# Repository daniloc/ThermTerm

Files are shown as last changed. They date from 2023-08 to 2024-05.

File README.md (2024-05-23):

# ThermTerm: an open source heat pump controller and home automation terminal, built on ESP32

264734232-c3d5e749-000b-4d88-8361-5ec403e4682f

**Control heat pumps manually or remotely via MQTT/Home Assistant**.

I love my heat pumps. They're energy efficient and the fastest way to heat or cool any room.

But I've always hated the remote controls that come with heat pumps. They're clunky and hard to read, especially in low light. In theory, you can program schedules for your heat pumps, but in practice the remotes are too frustrating to use for that.

ThermTerm solves all the problems I've had with these physical controls, while integrating the heat pumps into Home Assistant via MQTT. Additional sensors pipe temperature, humidity and light data, for statistics and automation. Out of the box, ThermTerm supports Mitsubishi's infrared protocol, since that's the system I have. Thanks to integration with [IRRemoteESP8266](https://github.com/crankyoldgit/IRremoteESP8266), you can make ThermTerm work with [your own heat pumps](https://github.com/crankyoldgit/IRremoteESP8266/blob/master/SupportedProtocols.md) by writing a few lines of adaptor code. No signal analysis or reverse-engineering required. See [Customization](#customization) for more details.

**Note: you will need [PlatformIO](https://platformio.org) to get started.**

## Interface

Diagram

Press the dial to toggle power.

Turn the dial to set temperature.

Change to heat mode with the bottom button, cool mode with the top. Set fan speed by pressing the center button, then turn the dial.

Through a TFT screen, readouts are visible any time of day. The chunky dial is easy to press without looking. Program automations using Home Assitant, not miserable rubber buttons like a VCR. Toggle your heat pumps from any room in the house, or even while you're away.

## Goals

- Make a heat pump controller I don't hate using
- Use easy-to-repurpose IR, instead of a manufacturer-specific serial connection
- Structure this project into discrete objects to make iteration, maintenance and enhancements easy
- Provide hobbyists with a reference for Arduino code with that kind of structure (I had a hard time finding it for end projects, only libraries)
- Build a device that expands the surface area of a home automation system, letting it gather more data, take more user input, and provide more feedback
- Leverage as much of the existing Arduino OSS code ecosystem as possible, keeping the project tightly scoped to its problem domain

## Shoutouts/core dependencies

- [Adafruit](https://learn.adafruit.com), whose thorough libraries and thoughtful breakout boards made hardware integration a breeze
- [`IRRemoteESP8266`](https://github.com/crankyoldgit/IRremoteESP8266), a library with bulletproof software-based PWM, a great API, and a shocking compendium of IR protocols
- [`arduino-home-assistant`](https://github.com/dawidchyrzynski/arduino-home-assistant), an MQTT library with exhaustive implementations of Home Assistant-supported devices

## Bill of materials

- [Adafruit ESP32-S3 Feather Reverse TFT](https://www.adafruit.com/product/5691)
- [Adafruit I2C rotary encoder board with Neopixel](https://www.adafruit.com/product/4991)
- [Rotary encoder](https://www.adafruit.com/product/377)
- [IR blaster board](https://www.adafruit.com/product/5639)
- Optional: 5mm IR LED
- Optional: [Tiny piezo buzzer](https://www.adafruit.com/product/1740), for auditory feedback now (and later: alerts)
- Optional: [400 mAh LiPo battery](https://www.adafruit.com/product/3898), so the devices can still communicate with HA during a power outage
- [SHTC3 Temperature/humidity sensor](https://www.adafruit.com/product/4636)
- [BH1750 Light sensor](https://www.adafruit.com/product/4681)
- 1 [100mm StemmaQT/Qwiic cable](https://www.adafruit.com/product/4210)
- 2 [50mm StemmaQT/Qwiic cables](https://www.adafruit.com/product/4399)
- Wires for the IR blaster (I trimmed one of [these](https://www.adafruit.com/product/4336))
- USB-C cable ([right angle designs](https://www.amazon.com/dp/B08912ZBHZ) look best)
- A 5v USB power supply
- Opaque PETG to print the main case
- Translucent PETG to print the dial
- [Velcro/picture hanging Command Strip](https://www.amazon.com/Command-Picture-Decorate-Damage-Free-PH206-14NA/dp/B073XR4X72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) to wall-mount

The sensors use I2C, so with a light rewrite, you can replace the above models with alternatives if needed, or skip them entirely if you don't care about recording data back to Home Assistant.

If you want to design your own enclosure and use a different display, I suspect any ESP32-based device will work fine.

There's not a huge upside to the battery in the current implementation but I designed the case to accommodate it for future enhancements. You can skip it unless you want to tinker with power outage-related home automation tasks.

## Configuration

Make a copy of [`_Credentials.h.example`](/src/_Credentials.h.example), rename it to `_Credentials.h`. This file will be ignored by git.

Fill in these values as appropriate to your network:

```C++
#define WIFI_SSID ""       // your network SSID (name)
#define WIFI_PASSWORD "" // your network password

#define MQTT_LOGIN ""
#define MQTT_PASSWORD ""

#define MQTT_BROKER IPAddress(192, 168, 1, 100)
```

## Home Assistant

With correct MQTT credentials, ThermTerm should be discovered automatically in the Home Assistant MQTT configuration.

**To troubleshoot, uncomment this line in `platfomio.ini`:**

```yaml
build_flags = -D ARDUINOHA_DEBUG
```

This will log MQTT events and errors via serial.

## Customization

The most urgent customization for most will be making this work with your own heat pump.

1. Write a subclass of [`IRInterface`](/src/hardware/infrared/IRInterface.h). You can use [`MistubishiInterface`](https://github.com/daniloc/ThermTerm/blob/main/src/hardware/infrared/MitsubishiInterface.cpp) as a starting point. The goal is to translate the system controller's state model into whatever features you care about for your own heat pump. Consult IRremoteESP8266 for [the API that corresponds to your manufacturer](https://github.com/crankyoldgit/IRremoteESP8266/blob/master/SupportedProtocols.md).
2. In `main.cpp`, replace the `MitsubishiInterface` instance in the `SystemController` constructor with your own interface:

```C++
    YourCustomInterface customInterface;
    SystemController controller(customInterface);
```

That should get you moving.

To tweak other details about the device, explore `_Constants.h`. To adapt this to alternative hardware, including other displays, you'll want to replace the implementations in `src/hardware`.

## Assembly

If you want to go all-in and asemble one of these for yourself, 3D printing files have been provided. See [ASSEMBLY.md](/enclosure/ASSEMBLY.md) for detailed instructions.

## Roadmap

There's a lot more this platform could do, but this is the minimally-useful implementation that can get your whole heat pump system integrated in with an afternoon of work. Future features:

- [ ] Celsius support (what can I say, I think in Fahrenheit)
- [ ] Display alerts issued from Home Assistant
- [ ] Trigger alerts distributed to all other ThermTerm devices on the network
- [ ] Set preferences, including WiFi and MQTT credentials, via serial terminal
- [ ] Bulk provisioning

## Contributions

If you have anything useful you'd like to give back, feel free. Of particular interest:

- A simple Celsius toggle. A preprocessor macro would be fine to start with. All the internal state is managed in Celsius, and `SystemState` already has partial support for it.
- I can only test with Mitsubishi 144-bit IR receivers, since that's all I have. If you have a working interface for a different manufacturer, open a PR to add it!
- This is the most C++ I've ever written. If there's anything goofy that could be done differently, feel free to propose it
- Relatedly, if you have thoughts on making this project more extensible with other displays and ESP32 variants, I'd love to hear about it
- Enhancements to documentation, or comments on code you found confusing, are great too

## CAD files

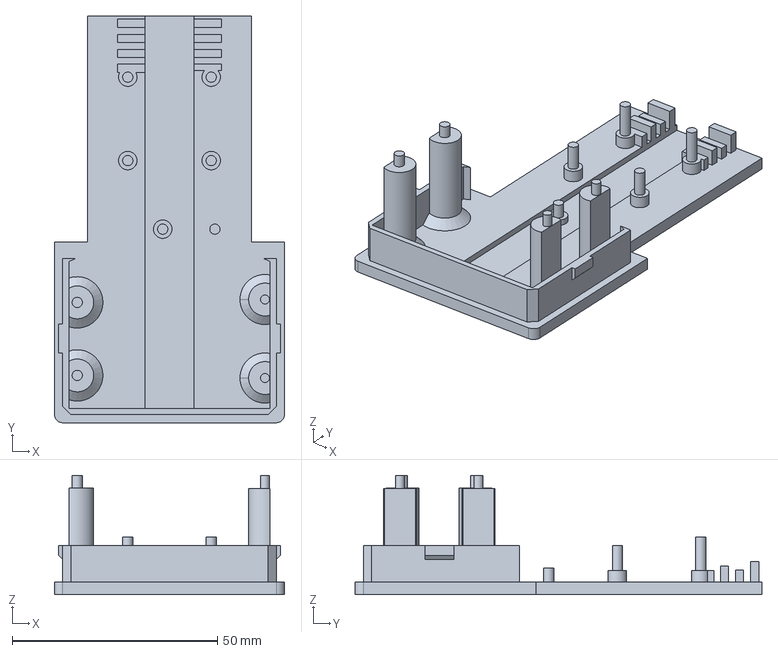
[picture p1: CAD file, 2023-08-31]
enclosure/ThermTerm case 1.2_Base plate.step
56.0 x 99.0 x 29.0 mm

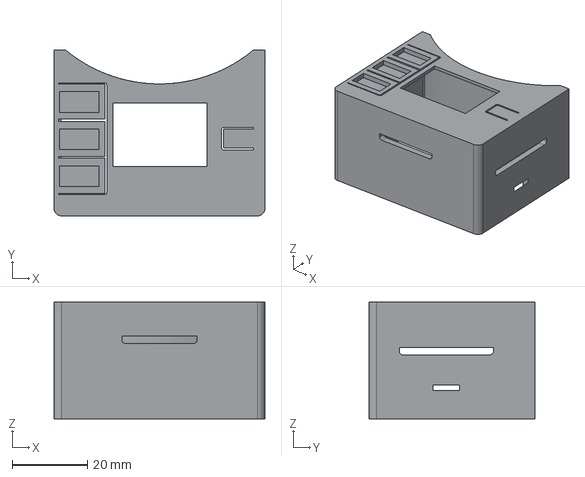
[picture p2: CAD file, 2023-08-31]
enclosure/ThermTerm case 1.2_Top case.step
56.0 x 44.0 x 31.0 mm

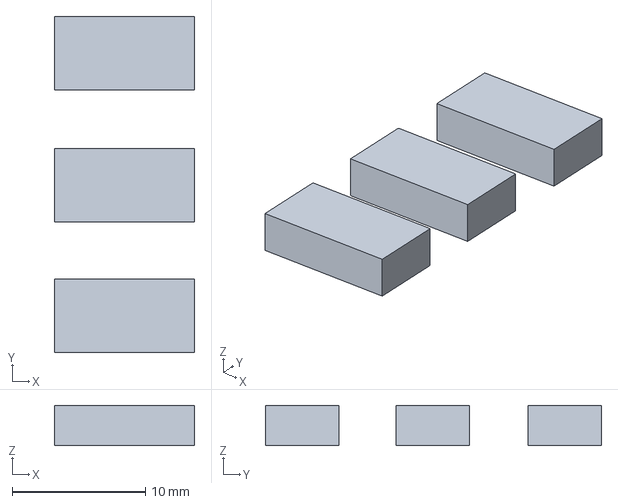
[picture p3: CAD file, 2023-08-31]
enclosure/ThermTerm case 1.2_Keycaps.step
10.5 x 25.2 x 3.00 mm

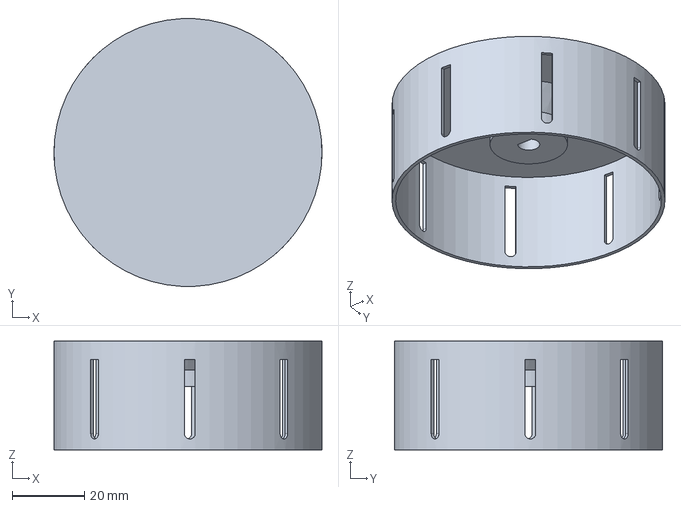
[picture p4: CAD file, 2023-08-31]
enclosure/ThermTerm case 1.2_Knob.step
74.0 x 74.0 x 30.0 mm

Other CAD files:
enclosure/ThermTerm case 1.2_Base plate.stl
enclosure/ThermTerm case 1.2_Keycaps.stl
enclosure/ThermTerm case 1.2_Knob.stl
enclosure/ThermTerm case 1.2_Top case.stl

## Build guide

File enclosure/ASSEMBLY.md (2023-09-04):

# Assembly

To build your own ThermTerm, follow along.

## Circuit

ThermTerm relies mostly on I2C devices, so you can connect them together in whatever order you want. You can affix these components to a piece of cardboard to test things out and ensure everything is doing what you expect.

264531564-6f04c1c9-9900-47f6-958d-a4b7f66801d4

If you'd like to use the included enclosure design, this sequence works best:

Circuit diagram

By default, the infrared signal pin is `A0`, while the piezo signal is on `A1`. Change these in `_Constants.h` if needed. Oddly, the Feather only has a single ground pin on the board proper, so I snuck the piezo's ground wire into the IR blaster ground's solder blob. Seems to be fine.

## 3D printing

For something you can mount to the wall, a case design is provided. You'll want to orient all parts with their flattest faces against the print bed.

Printing layout example

The design looks and works great using draft-quality layers at 0.3mm, but **you'll want to use PETG for the print**. While prototyping the case, I found PLA to be too brittle for the various posts that hold the components in place.

If your bridging is well tuned, you shouldn't need supports.

The knob/dial piece really should be printed with translucent PETG. This allows you to see the status light on the rotary encoder, and it's probably important for the IR signal to escape as well. If you want to be fancy, it's nice to ask your slicer for a more interesting bottom infill pattern, since light will shine through it. In PrusaSlicer, I chose `Octagram Spiral`.

## Assembly

To use the included case design, wire up the components as described above. Sensors are held in place by slots, while posts hold the IR blaster, rotary encoder, and ESP32 board in place.

The IR blaster leads should be trimmed to around 50mm.





I affixed the small piezo buzzer to the metal RF shield on the ESP32 board to keep it out of the way.



The rotary encoder breakout gets a lot of impact, so I'd suggest anchoring it in place by melting the bottom two posts with a soldering iron.



To manage the StemmaQT cables, use the raceway molded into the base to tuck the longest cable run, from ESP32 to the light sensor. For the shorter cables, fold them gently against the case to prevent the dial scraping against them.



If desired, print the key caps and press-fit them into the rectangular recesses on the buttons in front of the case. I found it helped to remove the front face, position the key caps as best I could manage, then place the shell face down and gently press against the insides of the button tabs with the rubberized handle-end of some pliers. This clicked the keycaps into place without bending the tabs.



Pop on the dial, and you're done.

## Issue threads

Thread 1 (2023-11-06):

Compatible Heat Pumps

JacobChrist, 2023-11-06:
It would be nice if you had a list of compatible heat pumps that you have tested this device with.  It sounds like you are using room scale units.  I have a large house with small bedrooms and I have been thinking about putting in room scale AC's so that I don't have to cool the huge house at night when the vast majority of the space is unoccupied.

Nice project!  I want to do something similar but I'll probably use something like this [EarthLCD 303 with a Pico Pi](https://github.com/earthlcd/EarthPK-3x) display  which I already have working with [PicoW_HomeAssistant_Starter](https://github.com/daniloc/PicoW_HomeAssistant_Starter).

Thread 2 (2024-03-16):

Modified the base model to screw on components

ecodad, 2024-03-16:
I modified your model to be able to screw on 3 of the boards with m2.5x4 screws.

I posted the stl on [Printables](https://www.printables.com/model/807892-modified-thermterm-base), let me know if you want me to change anything in the description or attribution.  I included your license as a text file.
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

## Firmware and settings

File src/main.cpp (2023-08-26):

#include <Arduino.h>
#include <Adafruit_ST7789.h>

#include "views/BaseView.h"
#include "hardware/Display.h"
#include "hardware/EnvSensor.h"
#include "hardware/Audio.h"
#include "hardware/input/Input.h"
#include "hardware/infrared/MitsubishiInterface.h"

#include "views/StatusView.h"
#include "SystemController.h"

#include "hardware/WifiInterface.h"
#include <WiFi.h>

MitsubishiInterface mitsubishiInterface; // Create alternative IR schemes by sublassing IRInterface
SystemController controller(mitsubishiInterface);

EnvSensor sensor = EnvSensor();

Input &input = Input::shared();
Adafruit_ST7789 &tft = Display::shared().configure();
StatusView statusView(tft, controller);
BaseView &activeView = statusView;

void handleInput(UserInput input)
{
  Serial.print(F("forwarded input"));
  activeView.handleInputEvent(input);
}

void updateEnvironmentData(float temp, float humidity, float lux)
{

  if (temp != controller.getState().temperature ||
      humidity != controller.getState().humidity ||
      lux != controller.getState().lux)
  {
    controller.setHumidity(humidity);
    controller.setTemperature(temp);
    controller.setLux(lux);
    statusView.draw();
  }

  if (controller.shouldDimScreen())
  {
    Display::shared().dimScreen();
  }
  else
  {
    Display::shared().brightScreen();
  }
}

void setup(void)
{
  Serial.begin(9600);
  Serial.print(F("Hello! Feather TFT Test"));

  sensor.setCallback(updateEnvironmentData);
  input.setCallback(handleInput);

  sensor.configure();
  input.configure();
  statusView.draw();

  Audio::configure();

  WifiInterface::shared().configure();
  controller.configure();
}

void loop()
{
  sensor.heartbeat();
  input.heartbeat();
  controller.heartbeat();
  statusView.heartbeat();
}

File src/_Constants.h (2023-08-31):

#ifndef SRC_CONSTANTS
#define SRC_CONSTANTS

#include <Arduino.h>

#define INFRARED_PIN A0

#define HVAC_MAX_TEMP 31 // Celsius values
#define HVAC_MIN_TEMP 16

#define DIM_SCREEN_CUTOFF_LUX 5 // What light value should turn off the mode indicator and dim the screen?

#define PWM_TONE_CHANNEL 2 // Get off the main PWM channel, or LED pulses will leak out the speaker
#define PIEZO_PIN A1
#define PIEZO_BASE_FREQUENCY 200

#define UI_CHIRP_NOTE_LENGTH 25

#define SCREEN_WIDTH 240  // display width, in pixels
#define SCREEN_HEIGHT 135 // display height, in pixels

#define ENV_SENSOR_INTERVAL 5 // Seconds between polling the sensors

const int BUTTON0_PIN = 0;
const int BUTTON1_PIN = 1;
const int BUTTON2_PIN = 2;

#define VERSION_NUMBER "0.2"

#define ROTARY_ENCODER_ADDRESS 0x36
#define ENCODER_SWITCH_PIN 24
#define ENCODER_NEOPIXEL_PIN 6

#endif // SRC_CONSTANTS

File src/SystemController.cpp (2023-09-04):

#include "hardware/infrared/MitsubishiInterface.h"
#include "hardware/Audio.h"
#include "SystemController.h"
#include "_Constants.h"

#include <functional>

SystemController *SystemController::instance = nullptr; // Initialize static member

float setPointStep = 1;

SystemController::SystemController(IRInterface &irInterface) : haInterface_(HAInterface()),
                                                           irInterface_(irInterface)
{
    instance = this;
}

bool SystemController::shouldDimScreen()
{
    return state_.lux < DIM_SCREEN_CUTOFF_LUX;
}

void SystemController::scheduleUpdate()
{
    needsUpdate = true;
    batchScheduleTime = 0;
}

void SystemController::checkInputBatching()
{
    if (!needsUpdate)
        return;

    if (batchScheduleTime == 0)
    {
        batchScheduleTime = millis();
        return;
    }

    if (millis() - batchScheduleTime >= 2000)
    {
        sendInfraredCommand();
        needsUpdate = false;
        batchScheduleTime = 0;
    }
}

void SystemController::sendInfraredCommand()
{
    irInterface_.sendCommand(state_.hvacCommand());
}

HvacMode convertMode(HAHVAC::Mode mode)
{
    switch (mode)
    {
    case HAHVAC::AutoMode:
        return HVAC_AUTO;
    case HAHVAC::CoolMode:
        return HVAC_COLD;
    case HAHVAC::HeatMode:
        return HVAC_HOT;
    case HAHVAC::DryMode:
        return HVAC_DRY;
    case HAHVAC::FanOnlyMode:
        return HVAC_FAN;
    default:
        return HVAC_AUTO; // default value
    }
}

HAHVAC::Mode reverseConvertMode(HvacMode mode)
{
    switch (mode)
    {
    case HVAC_AUTO:
        return HAHVAC::AutoMode;
    case HVAC_COLD:
        return HAHVAC::CoolMode;
    case HVAC_HOT:
        return HAHVAC::HeatMode;
    case HVAC_DRY:
        return HAHVAC::DryMode;
    case HVAC_FAN:
        return HAHVAC::FanOnlyMode;
    default:
        return HAHVAC::AutoMode; // default value
    }
}

HvacFanMode convertFanMode(HAHVAC::FanMode haFanMode)
{
    switch (haFanMode)
    {
    case HAHVAC::AutoFanMode:
        return FAN_SPEED_AUTO;
    case HAHVAC::LowFanMode:
        return FAN_SPEED_1;
    case HAHVAC::MediumFanMode:
        return FAN_SPEED_3;
    case HAHVAC::HighFanMode:
        return FAN_SPEED_4;
    default:
        return FAN_SPEED_AUTO;
    }
}

void SystemController::handleRemoteModeChange(HAHVAC::Mode newMode, HAHVAC *sender)
{
    if (newMode == HAHVAC::Mode::OffMode)
    {
        state_.power = OFF;
    }
    else
    {
        state_.hvacMode = convertMode(newMode);
        state_.power = ON;
    }

    sender->setMode(newMode);
    sendInfraredCommand();
    notifyObservers();
}

void SystemController::handleRemotePowerChange(bool powerState, HAHVAC *sender)
{
    if (powerState)
    {
        state_.power = ON;
        haInterface_.getHVACDevice().setMode(sender->getCurrentMode());
    }
    else
    {
        state_.power = OFF;
        haInterface_.getHVACDevice().setMode(HAHVAC::Mode::OffMode);
    }

    sendInfraredCommand();
    notifyObservers();
}

void SystemController::handleRemoteFanModeChange(HAHVAC::FanMode fanMode, HAHVAC *sender)
{
    Serial.print("updating fan mode" + String(fanMode));
    state_.fanSpeed = convertFanMode(fanMode);
    state_.power = ON;
    sender->setFanMode(fanMode);
    sendInfraredCommand();
    notifyObservers();
}

void SystemController::handleRemoteTargetTemperatureChange(HANumeric temperature, HAHVAC *sender)
{
    Serial.print("receiving remote temperature change");
    setSetPoint(temperature.toFloat());
}

void SystemController::configure()
{
    irInterface_.configure();
    haInterface_.configure(state_.celsius);

    haInterface_.getHVACDevice().onModeCommand(&SystemController::staticHandleRemoteModeChange);
    haInterface_.getHVACDevice().onPowerCommand(SystemController::staticHandleRemotePowerChange);
    haInterface_.getHVACDevice().onFanModeCommand(SystemController::staticHandleRemoteFanModeChange);
    haInterface_.getHVACDevice().onTargetTemperatureCommand(SystemController::staticHandleRemoteTargetTemperatureChange);

    haInterface_.getAlertTrigger().onCommand(SystemController::staticHandleAlert);
}

// getters
SystemState SystemController::getState() { return state_; };

// setters
void SystemController::setTemperature(float temperature)
{
    if (temperature != state_.temperature)
    {
        state_.temperature = temperature;
        haInterface_.getTemperatureSensor().setValue(temperature);
        Serial.print(F("logging temp update"));
    }
}

void SystemController::setHumidity(float humidity)
{
    if (humidity != state_.humidity)
    {
        state_.humidity = humidity;
        haInterface_.getHumiditySensor().setValue(humidity);
        Serial.print(F("logging humidity update"));
    }
}

void SystemController::setLux(float lux)
{
    if (lux != state_.lux)
    {
        state_.lux = lux;
        haInterface_.getLightSensor().setValue(lux);
        Serial.print(F("Logging light update"));
    }
}

void SystemController::setSetPoint(float setPoint)
{
    if (setPoint != state_.getSetPointUIValue())
    {
        state_.updateSetPoint(setPoint);
        haInterface_.getHVACDevice().setTargetTemperature(setPoint);
        scheduleUpdate();
        notifyObservers();
    }
}

void SystemController::setHVACMode(HvacMode hvacMode)
{

    state_.hvacMode = hvacMode;
    state_.power = ON;
    haInterface_.getHVACDevice().setMode(reverseConvertMode(hvacMode));
    sendInfraredCommand();
    notifyObservers();
}

void SystemController::setFanSpeed(HvacFanMode fanSpeed)
{

    state_.fanSpeed = fanSpeed;
    scheduleUpdate();
}

void SystemController::incrementSetPoint()
{
    float setPoint = state_.getSetPointUIValue();
    setPoint += setPointStep;
    setSetPoint(setPoint);
    Audio::play_UpwardTone();
}

void SystemController::decrementSetPoint()
{
    float setPoint = state_.getSetPointUIValue();
    setPoint -= setPointStep;
    setSetPoint(setPoint);
    Audio::play_DownwardTone();
}

void SystemController::togglePower()
{

    if (state_.power == ON)
    {
        state_.power = OFF;
        haInterface_.getHVACDevice().setMode(HAHVAC::Mode::OffMode);
    }
    else
    {
        state_.power = ON;
        haInterface_.getHVACDevice().setMode(reverseConvertMode(state_.hvacMode));
    }

    needsUpdate = false;
    sendInfraredCommand();
    notifyObservers();
}

void SystemController::heartbeat()
{
    haInterface_.heartbeat();
    checkInputBatching();
}

// Static->Instance bridging
void SystemController::staticHandleRemotePowerChange(bool powerState, HAHVAC *sender)
{
    if (instance)
    {
        instance->handleRemotePowerChange(powerState, sender);
    }
}

void SystemController::staticHandleRemoteFanModeChange(HAHVAC::FanMode fanMode, HAHVAC *sender)
{
    if (instance)
    {
        instance->handleRemoteFanModeChange(fanMode, sender);
    }
}
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

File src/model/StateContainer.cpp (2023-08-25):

#include "hardware/MitsubishiInterface.h"
#include "hardware/Audio.h"
#include "StateContainer.h"

#include <functional>

#define DIM_SCREEN_CUTOFF_LUX 1

StateContainer *StateContainer::instance = nullptr; // Initialize static member

MitsubishiInterface mitsubishiSend;

float setPointStep = 1;

bool StateContainer::shouldDimScreen()
{
    return stateData_.lux < DIM_SCREEN_CUTOFF_LUX;
}

void StateContainer::scheduleUpdate()
{
    needsUpdate = true;
    batchScheduleTime = 0;
}

void StateContainer::checkInputBatching()
{
    if (!needsUpdate)
        return;

    if (batchScheduleTime == 0)
    {
        batchScheduleTime = millis();
        return;
    }

    if (millis() - batchScheduleTime >= 2000)
    {
        sendInfraredCommand();
        needsUpdate = false;
        batchScheduleTime = 0;
    }
}

void StateContainer::sendInfraredCommand()
{
    mitsubishiSend.sendHvacMitsubishi(stateData_.hvacMode, stateData_.heatPumpSetPoint(), stateData_.fanSpeed, HvacVanneMode::VANNE_AUTO, stateData_.power);
}

StateContainer::StateContainer() : haInterface_(HAInterface())
{
    instance = this;
}

HvacMode convertMode(HAHVAC::Mode mode)
{
    switch (mode)
    {
    case HAHVAC::AutoMode:
        return HVAC_AUTO;
    case HAHVAC::CoolMode:
        return HVAC_COLD;
    case HAHVAC::HeatMode:
        return HVAC_HOT;
    case HAHVAC::DryMode:
        return HVAC_DRY;
    case HAHVAC::FanOnlyMode:
        return HVAC_FAN;
    default:
        return HVAC_AUTO; // default value
    }
}

HAHVAC::Mode reverseConvertMode(HvacMode mode)
{
    switch (mode)
    {
    case HVAC_AUTO:
        return HAHVAC::AutoMode;
    case HVAC_COLD:
        return HAHVAC::CoolMode;
    case HVAC_HOT:
        return HAHVAC::HeatMode;
    case HVAC_DRY:
        return HAHVAC::DryMode;
    case HVAC_FAN:
        return HAHVAC::FanOnlyMode;
    default:
        return HAHVAC::AutoMode; // default value
    }
}

HvacFanMode convertFanMode(HAHVAC::FanMode haFanMode)
{
    switch (haFanMode)
    {
    case HAHVAC::AutoFanMode:
        return FAN_SPEED_AUTO;
    case HAHVAC::LowFanMode:
        return FAN_SPEED_1;
    case HAHVAC::MediumFanMode:
        return FAN_SPEED_3;
    case HAHVAC::HighFanMode:
        return FAN_SPEED_5;
    default:
        return FAN_SPEED_AUTO;
    }
}

void StateContainer::handleRemoteModeChange(HAHVAC::Mode newMode, HAHVAC *sender)
{
    if (newMode == HAHVAC::Mode::OffMode)
    {
        stateData_.power = OFF;
    }
    else
    {
        stateData_.hvacMode = convertMode(newMode);
        stateData_.power = ON;
    }

    sender->setMode(newMode);
    sendInfraredCommand();
    notifyObservers();
}

void StateContainer::handleRemotePowerChange(bool powerState, HAHVAC *sender)
{
    if (powerState)
    {
        stateData_.power = ON;
        haInterface_.getHVACDevice().setMode(sender->getCurrentMode());
    }
    else
    {
        stateData_.power = OFF;
        haInterface_.getHVACDevice().setMode(HAHVAC::Mode::OffMode);
    }

    sendInfraredCommand();
    notifyObservers();
}

void StateContainer::handleRemoteFanModeChange(HAHVAC::FanMode fanMode, HAHVAC *sender)
{
    Serial.print("updating fan mode" + String(fanMode));
    stateData_.fanSpeed = convertFanMode(fanMode);
    stateData_.power = ON;
    sender->setFanMode(fanMode);
    sendInfraredCommand();
    notifyObservers();
}

void StateContainer::handleRemoteTargetTemperatureChange(HANumeric temperature, HAHVAC *sender)
{
    Serial.print("receiving remote temperature change");
    setSetPoint(temperature.toFloat());
}

void StateContainer::configure()
{
    mitsubishiSend.prepare();
    haInterface_.configure(stateData_.celsius);

    haInterface_.getHVACDevice().onModeCommand(&StateContainer::staticHandleRemoteModeChange);
    haInterface_.getHVACDevice().onPowerCommand(StateContainer::staticHandleRemotePowerChange);
    haInterface_.getHVACDevice().onFanModeCommand(StateContainer::staticHandleRemoteFanModeChange);
    haInterface_.getHVACDevice().onTargetTemperatureCommand(StateContainer::staticHandleRemoteTargetTemperatureChange);

    haInterface_.getAlertTrigger().onCommand(StateContainer::staticHandleAlert);
}

// getters
StateData StateContainer::getState() { return stateData_; };

// setters
void StateContainer::setTemperature(float temperature)
{
    if (temperature != stateData_.temperature)
    {
        stateData_.temperature = temperature;
        haInterface_.getTemperatureSensor().setValue(temperature);
        Serial.print(F("logging temp update"));
    }
}

void StateContainer::setHumidity(float humidity)
{
    if (humidity != stateData_.humidity)
    {
        stateData_.humidity = humidity;
        haInterface_.getHumiditySensor().setValue(humidity);
        Serial.print(F("logging humidity update"));
    }
}

void StateContainer::setLux(float lux)
{
    if (lux != stateData_.lux)
    {
        stateData_.lux = lux;
        haInterface_.getLightSensor().setValue(lux);
        Serial.print(F("Logging light update"));
    }
}

void StateContainer::setSetPoint(float setPoint)
{
    if (setPoint != stateData_.setPoint)
    {
        stateData_.setPoint = setPoint;
        haInterface_.getHVACDevice().setTargetTemperature(setPoint);
        scheduleUpdate();
        notifyObservers();
    }
}

void StateContainer::setHVACMode(HvacMode hvacMode)
{

    stateData_.hvacMode = hvacMode;
    stateData_.power = ON;
    haInterface_.getHVACDevice().setMode(reverseConvertMode(hvacMode));
    sendInfraredCommand();
    notifyObservers();
}

void StateContainer::setFanSpeed(HvacFanMode fanSpeed)
{

    stateData_.fanSpeed = fanSpeed;
    scheduleUpdate();
}

void StateContainer::incrementSetPoint()
{
    float setPoint = stateData_.setPoint;
    setPoint += setPointStep;
    setSetPoint(setPoint);
    Audio::play_UpwardTone();
}

void StateContainer::decrementSetPoint()
{
    float setPoint = stateData_.setPoint;
    setPoint -= setPointStep;
    setSetPoint(setPoint);
    Audio::play_DownwardTone();
}

void StateContainer::togglePower()
{

    if (stateData_.power == ON)
    {
        stateData_.power = OFF;
        haInterface_.getHVACDevice().setMode(HAHVAC::Mode::OffMode);
    }
    else
    {
        stateData_.power = ON;
        haInterface_.getHVACDevice().setMode(reverseConvertMode(stateData_.hvacMode));
    }

    sendInfraredCommand();
    notifyObservers();
}

void StateContainer::heartbeat()
{
    haInterface_.heartbeat();

    checkInputBatching();
}

// Static->Instance bridging
void StateContainer::staticHandleRemotePowerChange(bool powerState, HAHVAC *sender)
{
    if (instance)
    {
        instance->handleRemotePowerChange(powerState, sender);
    }
}

void StateContainer::staticHandleRemoteFanModeChange(HAHVAC::FanMode fanMode, HAHVAC *sender)
{
    if (instance)
    {
        instance->handleRemoteFanModeChange(fanMode, sender);
    }
}
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

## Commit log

2023-07-24 Add environment sensor, state management, and input manager
2023-07-24 Input forwards correctly to active view
    [StateContainer.cpp, main.cpp]
2023-07-26 Regular propagation to HA of sensor values
2023-07-30 Working linkage between HA and device
2023-07-30 Update screen based on mode and power state
2023-08-01 Cut down on brightness
2023-08-01 Mode select by button
2023-08-01 Add fan control with auto-dismiss
2023-08-12 Send PWM by hardware timer
2023-08-15 Add light sensor
2023-08-15 Batch updates to setpoint and fan mode
2023-08-15 Reset input scheduler when new input comes in
    [StateContainer.cpp]
2023-08-16 Add alert switch for later
2023-08-26 Encapsulate rotary encoder state and setup into a discrete class
2023-08-26 Replace button handling with AceButton
    [Input.cpp, _Constants.h]
2023-08-27 Replace IR transmission code with IRremoteESP8266 library
    [SystemController.cpp]
2023-08-30 Update assembly and readme details
2023-08-31 Add STL files
    [ThermTerm case 1.2_Base plate.stl, ThermTerm case 1.2_Keycaps.stl, ThermTerm case 1.2_Knob.stl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]
2023-08-31 Add Shapr3D and STEP files
    [ThermTerm case 1.2_Base plate.step, ThermTerm case 1.2_Keycaps.step, ThermTerm case 1.2_Knob.step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]
2023-09-04 fix: provide Mitsubishi IR encoder with celsius values
    [SystemController.cpp]
